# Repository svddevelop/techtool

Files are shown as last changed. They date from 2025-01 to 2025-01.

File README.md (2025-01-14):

( [RU](./README-RU.md) )
( [EN](./README.md) )
---

### TechTool

A tool built on the Raspberry Pi platform for monitoring vehicle electrical systems. It connects via the OBD2 port and uses onboard power. A smartphone, tablet, or laptop is intended to be used as the display.
Access is provided via WiFi (the Raspberry Pi works as an access point). Communication is done through a web interface or via an SSH terminal connection.

---

### Image

The image can be found in the `img` subdirectory. It is written to a USB drive of at least 4GB. It is based on the latest version of Raspberry Pi OS 64-bit.

***

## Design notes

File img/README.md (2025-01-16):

( [RU](./README-RU.md) )
( [DE](./README-DE.md) )
---

### Image
Image based on RASPBIAN OS (Debian 12)

`Linux techtool 6.6.69-v8+ #1835 SMP PREEMPT Thu Jan  2 11:27:29 GMT 2025 aarch64 GNU/Linux`

For installation on an SD card, you can use Balena Etcher, Raspberry Pi Imager, and others.

#### Connection Parameters:

- **User**: technik
- **Password**: technik
- **SSH Connection**: technik@techtool.local
- **WiFi Server IP**: 192.168.4.1

The USB-OTG port of the Raspberry Pi is configured to use the RNDIS Network. When connected to a Linux computer, it automatically connects. For Windows, you need to install a driver [such as this one](https://support.lenovo.com/ph/en/downloads/ds558735-rndis-driver-for-windows-10-lenovo-thinksystem-sr635-and-sr655).

Inside, the SPI-0.0 bus is configured with the ability to bring up the can0 interface. The following scripts are available for this:

- /usr/bin/up_can0.sh
- /usr/bin/candump_can0.sh
- /usr/bin/down_can0.sh

In addition, you can use the spi0 device directly when working with projects, for example, in Python. Do not forget to disable the can0 network interface using the down_can0.sh command before using other programs.

### WEB Interface

csws (console simple WEB server) is already installed in the system as a service **csws.service##. The file `/etc/csws.conf` contains a pre-configured setup, and by simply connecting to http://techtool.local/ or http://192.168.4.1/, the main browser page opens. It has a menu that calls pre-installed scripts. Their settings can be viewed, modified, or extended in the file `/etc/csws.conf`. Examples of HTML pages are located in the directory `/var/techtool/thtml`.

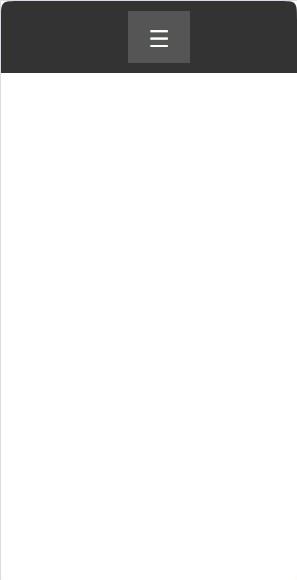
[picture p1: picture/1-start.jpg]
Start

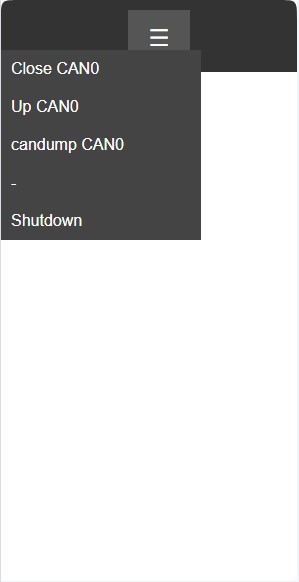
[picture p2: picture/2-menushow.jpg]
Menu

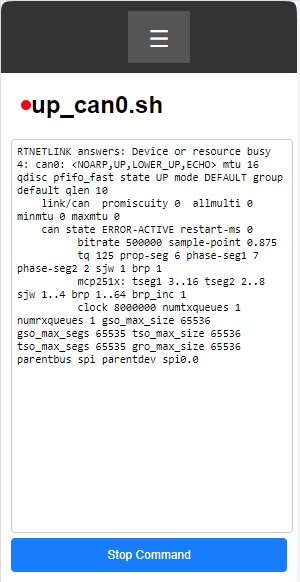
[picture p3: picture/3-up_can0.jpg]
Up can0


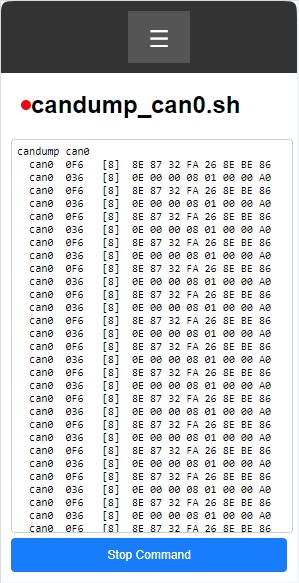
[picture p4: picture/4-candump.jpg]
candump can0

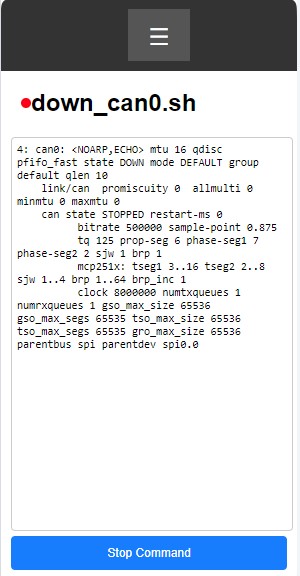
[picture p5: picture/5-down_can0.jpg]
Down can0


### Installation on Your Image

In the directory [techtool.install](./techtool.install), there are scripts for quickly making changes to the operating system files.

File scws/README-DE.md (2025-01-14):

( [RU](./README-RU.md) )
( [EN](./README.md) )
---

Der Server ist ein einfacher Skriptprozessor für Textdateien mit der Möglichkeit, Shell-Prozesse auszuführen und die Ausgabe an einen Browser zu streamen. Er kann als eigenständige Anwendung oder als Dienst betrieben werden.

### 1. Beschreibung der Hauptseite und des Skript-Interaktionsprinzips

Die Hauptseite kann neu konfiguriert werden, um eine andere Schnittstelle zu verwenden, aber hier wird erklärt, wie die Skripte miteinander interagieren.  
Die Hauptseite besteht aus einer festen Leiste mit einem Menübutton und einem Client-Bereich, in dem die Ergebnisse der ausgeführten Skripte angezeigt werden.  
Der Client-Bereich wird mit einem `<iframe>`-Element realisiert. Die Hauptseite enthält mehrere JavaScript-Hilfsfunktionen.  

Wenn der Menübutton geklickt wird, sendet die Funktion `loadMenu()` eine asynchrone AJAX-Anfrage an den Server. Nach Erhalt einer Antwort baut sie eine Baumstruktur der Menüelemente auf und zeigt sie dem Benutzer an.  

Wenn ein Menüelement ausgewählt wird, ändert JavaScript die `src`-Eigenschaft des `contentFrame` (iFrame)-Elements auf den Wert, der dem ausgewählten Menüelement entspricht. Auf diese Weise wird der Inhalt der neuen Anfrage innerhalb des Frames angezeigt.  

Eine weitere Hilfsfunktion ist `requestServer(URL)`. Sie sendet eine asynchrone Anfrage an den Server und gibt das Ergebnis zurück. Mit ihr können neue Variablen zum Server hinzugefügt, Menüelemente geändert und andere Aktionen durchgeführt werden.  

#### 1.1. Interne Server-URLs

##### 1.1.1. `/shell`
Führt einen Befehl aus, der im Parameter `cmd` übergeben wird. Implementiert in der Datei `shell.thtml`.  
Beispiel: `/shell?cmd=python myscript.py`  

##### 1.1.2. `/menulist`
Gibt eine Liste der Menüelemente und ihrer Befehle zurück. Standardmäßig werden sie aus der Konfigurationsdatei gelesen, können aber über die asynchrone Anfrage `/menu` geändert werden, die von der Funktion `requestServer()` gesendet wird.  

##### 1.1.3. `/menu`
Ermöglicht die Verwaltung des Menüs:  
- `/menu?clear` — löscht die Liste;  
- `/menu?default` — stellt die Liste aus der Konfigurationsdatei wieder her;  
- `/menu?captionX=Meine Beschriftung im Menü X&cmdX=meine URL` — ändert oder fügt ein Menüelement mit der angegebenen Beschriftung und URL hinzu.  
Alle Befehle können in einer Anfrage kombiniert werden. Sie werden in der Reihenfolge ausgeführt, die in der URL angegeben ist.  

##### 1.1.4. `/envvar`
Fügt eine neue Variable und ihren Wert zur Verwendung in Vorlagen hinzu.  
Beispiel: `/envvar?myvar=Mein Wert` — die Variable kann in der Vorlage als `$(myvar)` referenziert werden.  

##### 1.1.5. `/stop`
Beendet das Lauschen auf dem Port und beendet die Anwendung.  

##### 1.1.6. `/shellresponse`
Gibt alle ungelesenen Daten aus dem Ausgabestream zurück, nachdem ein Befehl über `/shell` ausgeführt wurde. Wenn kein Befehl ausgeführt wird, wird ein 404-Fehlercode zurückgegeben.  

##### 1.1.7. `/shellrun`
Gibt einen 200-Code zurück, wenn ein Befehl über `/shell` gestartet wurde. Andernfalls wird ein 404-Code zurückgegeben.  

### 2. Beschreibung der Konfigurationsdatei

#### 2.1. Abschnitt `Application`

##### 2.1.1. Parameter `Port`
Gibt den Port an, auf dem der Server auf Anfragen lauscht. Der Standardwert ist 8080. Bei Änderung des Ports muss der Zugriff über die Firewall konfiguriert werden. Zum Beispiel mit dem Tool `ufw`:  
```bash
sudo ufw allow 8080/tcp
```

##### 2.1.2. Parameter `RootPath`
Enthält den Pfad zum Verzeichnis mit den Vorlagen für angeforderte Seiten. Der Standardwert ist `/var/techtool/thtml/`, aber für Debugging-Zwecke kann ein anderes Verzeichnis verwendet werden.  

##### 2.1.3. Parameter `RootFileName`
Gibt den Namen der Vorlagendatei an, die beim Aufruf der URL `/` verwendet wird.  

##### 2.1.4. Parameter `WorkDir`
Enthält den Pfad zum Ordner für temporäre Dateien, wie z. B. Protokolle. Der Standardwert ist `/tmp`.  

#### 2.2. Abschnitt `MENU[X]`
Die Nummer im Abschnittsnamen ist obligatorisch und muss eindeutig sein.  

##### 2.2.1. Parameter `MenuCaption`
Enthält den Text, der dem Benutzer im Menü angezeigt wird.  

##### 2.2.2. Parameter `MenuCommand`
Enthält die URL der aufzurufenden Seite (siehe URL-Beschreibung).  

### 3. URL-Verarbeitung

Wenn ein Skriptname mit oder ohne Erweiterung angegeben wird, sucht der Server nach der Datei im Pfad, der in der Konfigurationsdatei (`APPLICATION.RootPath`) angegeben ist. Wenn die Datei nicht gefunden wird, erhält der Browser eine 404-Antwort.  

Wenn eine Seite angefordert wird, führt der Server die folgenden Substitutionen durch:  

#### 3.1. Konfigurationsvariablen
Im Skript müssen der Abschnittsname und der Parameter (ohne Trennzeichen) in Großbuchstaben angegeben werden.  
Beispiel: `$(APPLICATIONPORT)`  

#### 3.2. Umgebungsvariablen
Im Skript muss der Variablenname unter Berücksichtigung der Groß- und Kleinschreibung angegeben werden.  
Beispiel: `$(SHELL)`  

#### 3.3. Vom Entwickler definierte Variablen während der Shell-Ausführung
Die Bedingungen sind die gleichen wie für Umgebungsvariablen.  

### 4. Debugging von Skripten mit CSWS

In diesem Verzeichnis befinden sich drei vorkompilierte Versionen des Programms, die für verschiedene Plattformen entwickelt wurden:

- **`aarch64-linux`** — Version für Raspberry Pi-Geräte;
- **`x86_64-win64`** — Version für 64-Bit-Windows-Systeme;
- **`x86_64-linux`** — Version für 64-Bit-Linux-Systeme.

Das Starten der Anwendung mit einer separaten Konfigurationsdatei ermöglicht eine flexible Anpassung von Parametern und Vorlagen, was das Debugging von Skripten erleichtert. Dies ermöglicht es, ihre Funktionalität direkt im Browser zu testen, ohne Änderungen am Raspberry Pi-Gerät vornehmen zu müssen.

#### 4.1. Befehlszeilenparameter

Das Programm unterstützt die folgenden Befehlszeilenparameter:

- **`--conf="my.conf"`**  
  Startet das Programm mit der angegebenen Konfigurationsdatei. Dies ermöglicht die Verwendung von benutzerdefinierten Einstellungen und Vorlagen.

- **`--stop`**  
  Stoppt das Programm, falls es bereits ausgeführt wird.

- **`--envvar`**  
  Zeigt eine Liste aller Umgebungsvariablen an, die dem Programm zur Verfügung stehen.

- **`--addmenu="<menu caption>:=:<command>"`**  
  Fügt dem Konfigurationsdatei einen neuen Menüabschnitt hinzu.  
  - `<menu caption>` — der Menütitel;  
  - `<command>` — der mit diesem Menüpunkt verknüpfte Befehl.

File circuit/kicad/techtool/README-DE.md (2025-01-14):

( [EN](./README.md) )
( [RU](./README-RU.md) )
---

### Simplified Diagram

Alles ist mit vorgefertigten Modulen zusammengebaut, daher ist das Diagramm stark vereinfacht.

Das Diagramm zeigt die Verbindungen zwischen dem Raspberry Pi-Anschluss und dem MCP2515+TJA1050-Modul. Das Modul wird über den RPI +5V-Pin mit Strom versorgt. Allerdings weist das Modul einen Konstruktionsfehler auf und muss modifiziert werden. Die Stromversorgung für den TJA1050 sollte bei +5V bleiben, während der MCP2515 +3V3 benötigt. Der RPi-Pinout arbeitet mit 3 Volt, toleriert 5 Volt aufgrund interner Suppressoren und benötigt keinen Pegelwandler.

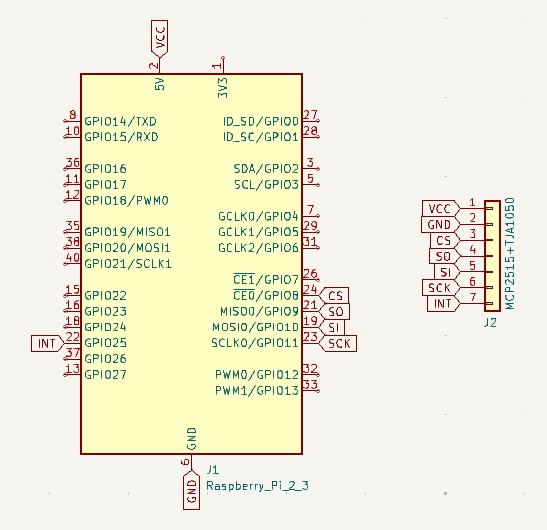
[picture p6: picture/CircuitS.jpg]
Simplified Connection Diagram


Daher wurde das MCP2515+TJA1050-Modul einigen Modifikationen unterzogen. Die Leiterbahnen auf beiden Seiten wurden durchtrennt, die Kontakte gereinigt und ein AS1117-3V3-Chip aufgelötet, um die Spannung von 5 Volt auf 3 Volt zu reduzieren.

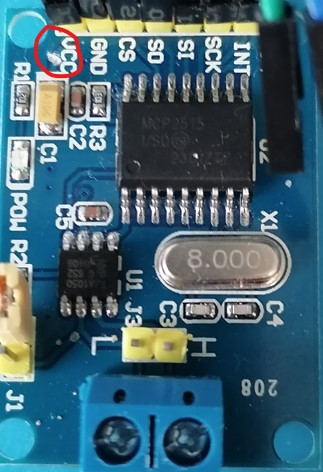
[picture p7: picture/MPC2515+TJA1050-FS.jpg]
MCP2515+TJA1050 Vorderseite

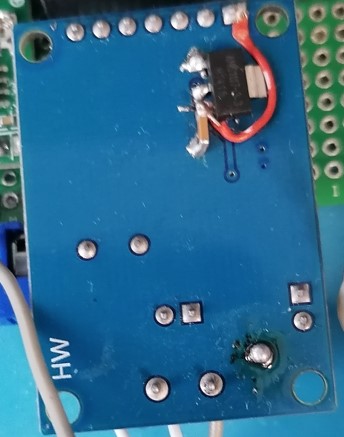
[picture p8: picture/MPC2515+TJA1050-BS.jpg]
MCP2515+TJA1050 Rückseite


>**Warning:**
Beim Anschluss der Schaltung an den OBD2-Bordstecker darf der Jumper J1 (120Ω-Terminator) nicht vergessen werden.

Da die Module über die Bordstromversorgung des OBD2-Steckers mit Strom versorgt werden müssen, wurde der MP1854 als STEP-Down-Regler gewählt, der mit einem Eingangsspannungsbereich von 5 bis 36 Volt arbeiten kann. Zusätzlich bietet er für kurze Zeit Kurzschlussschutz.

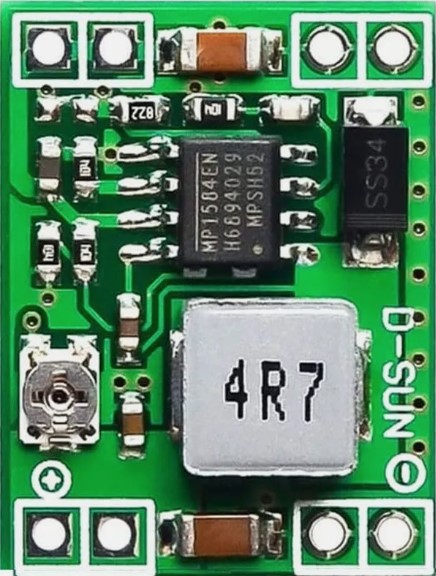
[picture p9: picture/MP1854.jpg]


Vor dem Anschluss des Reglers an den RPi muss die Ausgangsspannung mit dem Potentiometer auf den Bereich von 5 Volt eingestellt werden. Verbinden Sie ihn einfach mit den RPi +5V- und GND-Pins. Außerdem muss der GND-Pin mit Pin 4 des OBD2-Steckers verbunden werden, und der In+-Pin des Reglers muss mit Pin 16 des OBD2-Steckers verbunden werden.

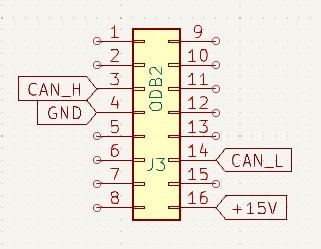
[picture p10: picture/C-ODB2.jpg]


>**Warning:**
Die Pin-Nummerierung auf dem Stecker ist im Diagramm korrekt dargestellt, aber in Wirklichkeit sind die Pins 9 bis 16 in umgekehrter Reihenfolge angeordnet, und Pin 16 befindet sich unter Pin 1.

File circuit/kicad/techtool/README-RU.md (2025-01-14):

( [EN](./README.md) )
( [DE](./README-DE.md) )
---

### Упрощенная схема

Все комплектуется готовыми блоками и потому схема сильно упрощена.

На схеме представлены соединения между разъемом Raspberry Pi и модулем MCP2515+TJA1050. Питание модуля берется с контакта RPI +5V. Но конструктивно модуля содержит ошибку и требуется его изменение. Питание для TJA1050 должно остаться +5V, а для MCP2515 требуется +3V3. RPi pinout работают с уровенем 3 вольта, толерантны к 5 вольтам за счет внутренних супрессоров, и не требуют преодразователя уровней.

Упрощенная схема соединений

Поэтому модуль MCP2515+TJA1050 получил некоторые изменения. Дорожки с двух сторон были перерезаны, контакты зачищены и напаяна микросхема AS1117-3V3_ которая и понижает напряжение с 5 вольт на 3 вольта.

MCP2515+TJA1050 Front side
MCP2515+TJA1050 Front side

>**Warning:**
При соединении схемы к бортовому разъему ODB2 не нужно забывать о включении перемычки J1 (терминатор 120Ω). 

Так как питание модулей необходимо проводить c бортового питания разъема ODB2, то в качестве STEP-Down регулятора был выбран MP1854,который может работать в диапазоне входного напряжения от 5 до 36 вольт. Помимо этого предоставляет на не продолжительное время защиту от короткого замыкания.

MP1854

Перед подключением регулятора к RPi необходимо выставить на нем выходное напряжение посредством потенционометра в диапазане 5 вольт. Просто соединить с контактами RPi +5V и GND. Также вывод GND должен соединяться с выводом 4 разъема ODB2, а вывод In+ регулятора с выводом 16 разъема ODB2.

MP1854

>**Warning:**
схематично нумерация контактов разъема указана правильно, но в реальности контакты с 9 по 16 идут в обратном направлении и вывод 16 находится под выводом 1.

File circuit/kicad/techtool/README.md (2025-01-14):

( [RU](./README-RU.md) )
( [DE](./README-DE.md) )
---

### Simplified Diagram

Everything is assembled using ready-made modules, so the diagram is greatly simplified.

The diagram shows the connections between the Raspberry Pi connector and the MCP2515+TJA1050 module. The module is powered from the RPI +5V pin. However, the module has a design flaw and requires modification. The power for the TJA1050 should remain +5V, while the MCP2515 requires +3V3. The RPi pinout operates at 3 volts, is tolerant to 5 volts due to internal suppressors, and does not require a level converter.

Simplified Connection Diagram

Therefore, the MCP2515+TJA1050 module has undergone some modifications. The traces on both sides were cut, the contacts were cleaned, and an AS1117-3V3 chip was soldered to step down the voltage from 5 volts to 3 volts.

MCP2515+TJA1050 Front Side
MCP2515+TJA1050 Back Side

>**Warning:**
When connecting the circuit to the OBD2 onboard connector, do not forget to include jumper J1 (120Ω terminator).

Since the modules need to be powered from the onboard power supply of the OBD2 connector, the MP1854 was chosen as the STEP-Down regulator, which can operate with an input voltage range of 5 to 36 volts. Additionally, it provides short-circuit protection for a short duration.

MP1854

Before connecting the regulator to the RPi, it is necessary to set the output voltage using the potentiometer to the range of 5 volts. Simply connect it to the RPi +5V and GND pins. Also, the GND pin must be connected to pin 4 of the OBD2 connector, and the In+ pin of the regulator must be connected to pin 16 of the OBD2 connector.

MP1854

>**Warning:**
The pin numbering on the connector is shown correctly in the diagram, but in reality, pins 9 to 16 are in reverse order, and pin 16 is located below pin 1.

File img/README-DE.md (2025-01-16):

( [RU](./README-RU.md) )
( [EN](./README.md) )
---

### Image
Image basierend auf RASPBIAN OS (Debian 12)

`Linux techtool 6.6.69-v8+ #1835 SMP PREEMPT Thu Jan  2 11:27:29 GMT 2025 aarch64 GNU/Linux`

Für die Installation auf einer SD-Karte können Sie Balena Etcher, Raspberry Pi Imager und andere verwenden.

#### Verbindungsparameter:

- **User**: technik
- **Password**: technik
- **SSH-Verbindung**: technik@techtool.local
- **WiFi-Server-IP**: 192.168.4.1

Der USB-OTG-Port des Raspberry Pi ist für die Verwendung des RNDIS-Netzwerks konfiguriert. Bei der Verbindung mit einem Linux-Computer erfolgt die Verbindung automatisch. Für Windows müssen Sie einen Treiber installieren, [wie zum Beispiel diesen](https://support.lenovo.com/ph/en/downloads/ds558735-rndis-driver-for-windows-10-lenovo-thinksystem-sr635-and-sr655).

Intern ist der SPI-0.0-Bus mit der Möglichkeit konfiguriert, die can0-Schnittstelle zu aktivieren. Dafür stehen folgende Skripte zur Verfügung:

- /usr/bin/up_can0.sh
- /usr/bin/candump_can0.sh
- /usr/bin/down_can0.sh

Zusätzlich können Sie das spi0-Gerät direkt verwenden, wenn Sie an Projekten arbeiten, zum Beispiel in Python. Vergessen Sie nicht, die can0-Netzwerkschnittstelle mit dem Befehl down_can0.sh zu deaktivieren, bevor Sie andere Programme verwenden.

### WEB-Oberfläche

csws (console simple WEB server) ist bereits als Dienst **csws.service## im System installiert. Die Datei `/etc/csws.conf` enthält eine vorkonfigurierte Einrichtung, und durch einfaches Verbinden mit http://techtool.local/ oder http://192.168.4.1/ öffnet sich die Hauptseite im Browser. Es gibt ein Menü, das vorkonfigurierte Skripte aufruft. Deren Einstellungen können in der Datei `/etc/csws.conf` angezeigt, geändert oder erweitert werden. Beispiele für HTML-Seiten befinden sich im Verzeichnis `/var/techtool/thtml`.

Start
Menü
Up can0

candump can0
Down can0

### Installation auf Ihrem Image

Im Verzeichnis [techtool.install](./techtool.install) befinden sich Skripte, um schnell Änderungen an den Betriebssystemdateien vorzunehmen.

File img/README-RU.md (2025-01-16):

( [EN](./README.md) )
( [DE](./README-DE.md) )

### Image
Image based on RASPBIAN OS (Debian 12)

`Linux techtool 6.6.69-v8+ #1835 SMP PREEMPT Thu Jan  2 11:27:29 GMT 2025 aarch64 GNU/Linux`

for installation on SD-Card you can use Balena Etche, Raspberry Pi Imager and etc.

#### Параметры соединения:

- **user** : technik
- **password** :technik
- **connection by ssh** : technik@techtool.local
- **WiFi-Server-IP** : 192.168.4.1

USB-OTG порт Raspberry Pi настроен на использование RNDIS Network. При подключении к компьютеру с Linux происходит автоматическое подключение. Для Windows нужно установить драйвер [например такой](https://support.lenovo.com/ph/de/downloads/ds558735-rndis-driver-for-windows-10-lenovo-thinksystem-sr635-and-sr655).

внутри настроена шина SPI-0.0 с возможностью поднять интерфейс can0. Для этого имеются следующие скрипты:

- /usr/bin/up_can0.sh
- /usr/bin/candump_can0.sh
- /usr/bin/down_can0.sh

Помимо этого можно использовать устройство spi0 напрямую при использовании проектов например на python. Не забудьте отключить сетевой интерфейс can0 командой down_can0.sh перед использованием других программ.

### WEB Interface

csws (console simple WEB server) уже установлен в сисмему в виде сервиса **csws.service##. В фале `/etc/csws.conf` имеется уже настроенная конфигурация и простым подключением http://techtool.local/ или http://192.168.4.1/ открывается основная страница браузера. На ней имеется меню, в котором вызываются предустановленные скрипты. Их настройки можно увидеть, изменить или дополнить в фале `/etc/csws.conf`. Примеры html-страниц располагаются в каталоге `/var/techtool/thtml`.

Start
Menu
Up can0

candump can0
Down can0

### установка на свой образ

в каталоге [techtool.istall](./techtool.install) расположены скрипты для быстрого внесения именений в файлы операционной системы.

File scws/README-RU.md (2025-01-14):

( [EN](./README.md) )
( [DE](./README-DE.md) )
---

Сервер представляет собой лёгкий обработчик текстовых скриптов с возможностью запуска шелл-процессов и вывода потока данных в браузер. Он может работать как отдельное приложение или как сервис.

### 1. Описание основной страницы и принцип взаимодействия скриптов

Основная страница может быть перенастроена для использования другого интерфейса, но здесь объясняется, как взаимодействуют скрипты между собой.  
Основная страница состоит из фиксированной панели с кнопкой меню и клиентской части, где отображаются результаты выполнения вызываемых скриптов.  
Клиентская часть реализована с использованием элемента `<iframe>`. Основная страница содержит несколько вспомогательных функций на JavaScript.  

При нажатии на кнопку меню функция `loadMenu()` отправляет асинхронный AJAX-запрос на сервер. Получив ответ, она строит дерево элементов меню и отображает его пользователю.  

При выборе элемента меню JavaScript изменяет свойство `src` элемента `contentFrame` (iFrame) на значение, соответствующее выбранному элементу меню. Таким образом, содержимое нового запроса отображается внутри фрейма.  

Ещё одна вспомогательная функция — `requestServer(URL)`. Она выполняет асинхронный запрос к серверу и возвращает результат. С её помощью можно добавлять новые переменные на сервер, изменять элементы меню и выполнять другие действия.  

#### 1.1. Внутренние URL сервера

##### 1.1.1. `/shell`
Запускает команду, переданную в параметре `cmd`. Реализовано в файле `shell.thtml`.  
Пример: `/shell?cmd=python myscript.py`  

##### 1.1.2. `/menulist`
Возвращает список элементов меню и их команд. По умолчанию они считываются из конфигурационного файла, но могут быть изменены с помощью запроса `/menu`, отправленного асинхронно функцией `requestServer()`.  

##### 1.1.3. `/menu`
Позволяет управлять меню:  
- `/menu?clear` — очищает список;  
- `/menu?default` — восстанавливает список из конфигурационного файла;  
- `/menu?captionX=My caption in menu X&cmdX=my URL` — изменяет или добавляет элемент меню с указанным заголовком и URL.  
Все команды можно комбинировать в одном запросе. Они выполняются в порядке, указанном в URL.  

##### 1.1.4. `/envvar`
Добавляет новую переменную и её значение для использования в шаблонах.  
Пример: `/envvar?myvar=My value` — переменная может быть вызвана в шаблоне как `$(myvar)`.  

##### 1.1.5. `/stop`
Останавливает прослушивание порта и завершает работу приложения.  

##### 1.1.6. `/shellresponse`
Возвращает все непрочитанные данные из потока вывода после выполнения команды через `/shell`. Если команда не выполняется, возвращается код ошибки 404.  

##### 1.1.7. `/shellrun`
Возвращает код 200, если команда была запущена через `/shell`. В противном случае возвращает код 404.  

### 2. Описание конфигурационного файла

#### 2.1. Секция `Application`

##### 2.1.1. Параметр `Port`
Указывает порт, на котором сервер будет прослушивать запросы. По умолчанию — 8080. При изменении порта необходимо настроить доступ через брандмауэр. Например, с помощью утилиты `ufw`:  
```bash
sudo ufw allow 8080/tcp
```

##### 2.1.2. Параметр `RootPath`
Содержит путь к каталогу с шаблонами запрашиваемых страниц. По умолчанию — `/var/techtool/thtml/`, но для отладки можно использовать любой другой.  

##### 2.1.3. Параметр `RootFileName`
Указывает имя файла шаблона, который будет использоваться при вызове URL `/`.  

##### 2.1.4. Параметр `WorkDir`
Содержит путь к папке для временных файлов, например логов. По умолчанию — `/tmp`.  

#### 2.2. Секция `MENU[X]`
Номер в названии секции обязателен и не должен повторяться.  

##### 2.2.1. Параметр `MenuCaption`
Содержит текст, отображаемый пользователю в меню.  

##### 2.2.2. Параметр `MenuCommand`
Содержит URL вызываемой страницы (см. описание URL).  

### 3. Обработка URL

При указании имени скрипта с расширением или без него производится поиск файла по пути, указанному в конфигурационном файле (`APPLICATION.RootPath`). Если файл не найден, браузер получает ответ с кодом 404.  

При запросе страницы сервер выполняет поиск и подстановку значений:  

#### 3.1. Конфигурационных переменных
В скрипте необходимо указать имя секции и параметра (без разделителя) в верхнем регистре.  
Например: `$(APPLICATIONPORT)`  

#### 3.2. Переменных окружения
В скрипте необходимо указать имя переменной с учётом регистра.  
Например: `$(SHELL)`  

#### 3.3. Переменных, заданных разработчиком при вызове шелла
Условия такие же, как и для переменных окружения.  

### 4. Отладка скриптов совместно с CSWS

В этом каталоге находятся три предварительно скомпилированные версии программы, предназначенные для разных платформ:

- **`aarch64-linux`** — версия для устройств на базе Raspberry Pi;
- **`x86_64-win64`** — версия для 64-битных систем Windows;
- **`x86_64-linux`** — версия для 64-битных систем Linux.

Запуск приложения с отдельным конфигурационным файлом позволяет гибко настраивать параметры и шаблоны, что упрощает отладку скриптов. Это дает возможность проверять их работу непосредственно в браузере без необходимости внесения изменений на устройстве Raspberry Pi.

#### 4.1. Параметры командной строки

Программа поддерживает следующие параметры командной строки:

- **`--conf="my.conf"`**  
  Запуск программы с использованием указанного конфигурационного файла. Это позволяет использовать индивидуальные настройки и шаблоны.

- **`--stop`**  
  Останавливает работу программы, если она уже запущена.

- **`--envvar`**  
  Выводит список всех переменных окружения, доступных для программы.

- **`--addmenu="<menu caption>:=:<command>"`**  
  Добавляет новую секцию меню в конфигурационный файл.  
  - `<menu caption>` — заголовок меню;  
  - `<command>` — команда, связанная с этим пунктом меню.

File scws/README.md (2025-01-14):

( [RU](./README-RU.md) )
( [DE](./README-DE.md) )
---

The server is a lightweight script processor for text files with the ability to run shell processes and stream the output to a browser. It can operate as a standalone application or as a service.

### 1. Description of the Main Page and Script Interaction Principle

The main page can be reconfigured to use a different interface, but here we explain how the scripts interact with each other.  
The main page consists of a fixed panel with a menu button and a client area where the results of the executed scripts are displayed.  
The client area is implemented using an `<iframe>` element. The main page contains several JavaScript helper functions.  

When the menu button is clicked, the `loadMenu()` function sends an asynchronous AJAX request to the server. Upon receiving a response, it builds a tree of menu items and displays it to the user.  

When a menu item is selected, JavaScript changes the `src` property of the `contentFrame` (iFrame) element to the value corresponding to the selected menu item. This way, the content of the new request is displayed inside the frame.  

Another helper function is `requestServer(URL)`. It performs an asynchronous request to the server and returns the result. It can be used to add new variables to the server, modify menu items, and perform other actions.  

#### 1.1. Internal Server URLs

##### 1.1.1. `/shell`
Executes a command passed in the `cmd` parameter. Implemented in the `shell.thtml` file.  
Example: `/shell?cmd=python myscript.py`  

##### 1.1.2. `/menulist`
Returns a list of menu items and their commands. By default, they are read from the configuration file, but they can be modified using the `/menu` request sent asynchronously by the `requestServer()` function.  

##### 1.1.3. `/menu`
Allows managing the menu:  
- `/menu?clear` — clears the list;  
- `/menu?default` — restores the list from the configuration file;  
- `/menu?captionX=My caption in menu X&cmdX=my URL` — modifies or adds a menu item with the specified caption and URL.  
All commands can be combined in a single request. They are executed in the order specified in the URL.  

##### 1.1.4. `/envvar`
Adds a new variable and its value for use in templates.  
Example: `/envvar?myvar=My value` — the variable can be referenced in the template as `$(myvar)`.  

##### 1.1.5. `/stop`
Stops listening on the port and terminates the application.  

##### 1.1.6. `/shellresponse`
Returns all unread data from the output stream after executing a command via `/shell`. If no command is running, a 404 error code is returned.  

##### 1.1.7. `/shellrun`
Returns a 200 code if a command was launched via `/shell`. Otherwise, it returns a 404 code.  

### 2. Description of the Configuration File

#### 2.1. `Application` Section

##### 2.1.1. `Port` Parameter
Specifies the port on which the server will listen for requests. The default is 8080. When changing the port, ensure firewall access is configured. For example, using the `ufw` utility:  
```bash
sudo ufw allow 8080/tcp
```

##### 2.1.2. `RootPath` Parameter
Contains the path to the directory with the templates for requested pages. The default is `/var/techtool/thtml/`, but any other directory can be used for debugging.  

##### 2.1.3. `RootFileName` Parameter
Specifies the name of the template file to be used when the URL `/` is called.  

##### 2.1.4. `WorkDir` Parameter
Contains the path to the folder for temporary files, such as logs. The default is `/tmp`.  

#### 2.2. `MENU[X]` Section
The number in the section name is mandatory and must be unique.  

##### 2.2.1. `MenuCaption` Parameter
Contains the text displayed to the user in the menu.  

##### 2.2.2. `MenuCommand` Parameter
Contains the URL of the page to be called (see URL description).  

### 3. URL Processing

When specifying a script name with or without an extension, the server searches for the file in the path specified in the configuration file (`APPLICATION.RootPath`). If the file is not found, the browser receives a 404 response.  

When a page is requested, the server performs the following substitutions:  

#### 3.1. Configuration Variables
In the script, specify the section name and parameter (without a separator) in uppercase.  
For example: `$(APPLICATIONPORT)`  

#### 3.2. Environment Variables
In the script, specify the variable name with case sensitivity.  
For example: `$(SHELL)`  

#### 3.3. Variables Defined by the Developer During Shell Execution
The conditions are the same as for environment variables.  

### 4. Debugging Scripts with CSWS

This directory contains three pre-compiled versions of the program, designed for different platforms:

- **`aarch64-linux`** — version for Raspberry Pi devices;
- **`x86_64-win64`** — version for 64-bit Windows systems;
- **`x86_64-linux`** — version for 64-bit Linux systems.

Launching the application with a separate configuration file allows for flexible customization of parameters and templates, making it easier to debug scripts. This enables testing their functionality directly in a browser without the need to make changes on the Raspberry Pi device.

#### 4.1. Command Line Parameters

The program supports the following command-line parameters:

- **`--conf="my.conf"`**  
  Launches the program using the specified configuration file. This allows for the use of custom settings and templates.

- **`--stop`**  
  Stops the program if it is already running.

- **`--envvar`**  
  Displays a list of all environment variables available to the program.

- **`--addmenu="<menu caption>:=:<command>"`**  
  Adds a new menu section to the configuration file.  
  - `<menu caption>` — the menu title;  
  - `<command>` — the command associated with this menu item.

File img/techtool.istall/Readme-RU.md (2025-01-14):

( [EN](./README.md) )
( [DE](./README-DE.md) )
---

### файлы для быстрой установки

##### Эти файлы обязательны для настройки системы:

- 1-change_etc-dhcpcd.sh
- 2-change_etc-dnsmasq.sh
- 3-change_etc_hostapd_hostapd.sh
- 4-install_csws_asservice.sh
- 5-do_copy_thtml.sh
- 6-create_setup_can0.sh
- 7-create_stop_can0.sh

##### Эти файлы лучше изменять вручную:

- change_cmdline.sh
- change_config.sh

##### Эти файлы использовать при необходимости:

- change_etc_sysctl.sh
- change_waitForNetwork.sh

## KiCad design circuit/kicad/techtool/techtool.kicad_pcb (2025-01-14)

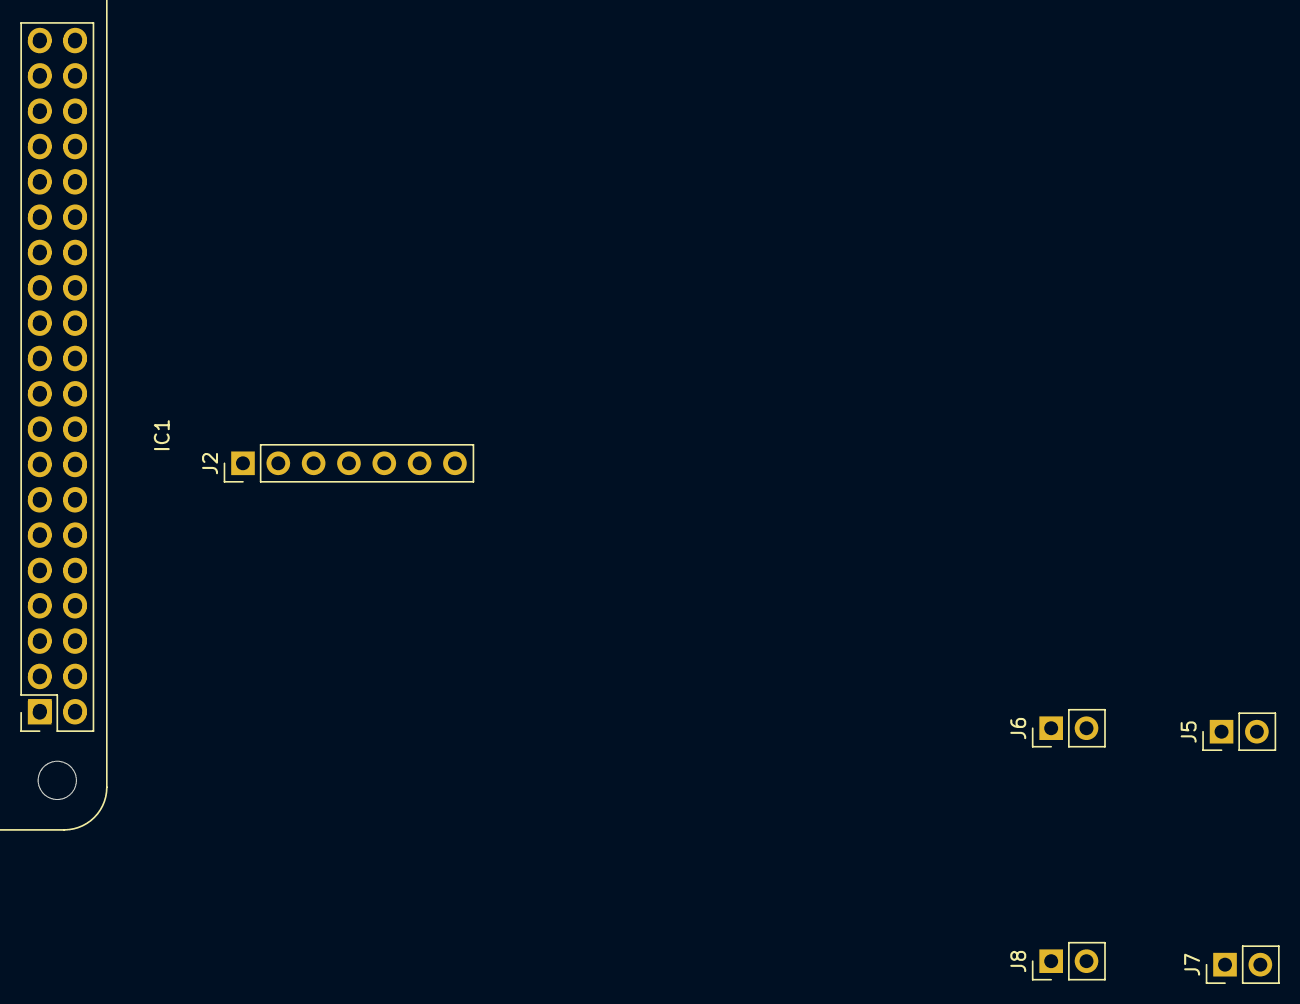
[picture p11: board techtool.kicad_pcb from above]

Board: 2 copper layers, 7 parts (1 on the bottom side), 8 nets, no tracks yet.

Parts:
IC1: Raspberry_Pi_Zero_W_(v1.3); Raspberry_Pi_Zero_Socketed_THT_FaceDown_MountingHoles
J1: Raspberry_Pi_2_3; PinHeader_2x20_P2.54mm_Vertical
J2: MCP2515+TJA1050; PinHeader_1x07_P2.54mm_Vertical
J5: VCC; PinHeader_1x02_P2.54mm_Vertical
J6: GND; PinHeader_1x02_P2.54mm_Vertical
J7: In+; PinHeader_1x02_P2.54mm_Vertical
J8: In-; PinHeader_1x02_P2.54mm_Vertical

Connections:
CS: J1.24 (~CE0/GPIO8), J2.3
GND: J1.6 (GND), J1.9 (GND), J1.14 (GND), J1.20 (GND), J1.25 (GND), J1.30 (GND), J1.34 (GND), J1.39 (GND), J2.2, J6.2
INT: J1.22 (GPIO25), J2.7
unnamed: J1.1 (3V3), J1.17 (3V3)
SCK: J1.23 (SCLK0/GPIO11), J2.6
SI: J1.19 (MOSI0/GPIO10), J2.5
SO: J1.21 (MISO0/GPIO9), J2.4
VCC: J1.2 (5V), J1.4 (5V), J2.1, J5.1

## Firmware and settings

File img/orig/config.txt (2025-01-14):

gpio=8=op,dh
dtparam=spi=off
#dtoverlay=spi-bcm2835-overlay
#dtoverlay=spi0-1cs,cs0_pin=8
dtoverlay=spi0-1cs
dtoverlay=mcp2515-can0,spi0-0,oscillator=16000000,interrupt=25
#,bitrate=500000




dtoverlay=dwc2

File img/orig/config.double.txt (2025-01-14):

# 
# MCP INT --> RPi 22 (GPIO 25); MCP SI --> RPi 19 (GPIO 10); MCP SO --> RPi 21 (GPIO 9)
# MCP SCK --> RPi 23 (GPIO 11); MCP CS --> RPi 24 (GPIO 8)
#

dtparam=spi=on
dtoverlay=mcp2515-can0,oscillator=8000000,interrupt=25

#
# MCP INT --> RPi 37 (GPIO 26); MCP SI --> RPi 38 (GPIO ); MCP SO --> RPi 35 (GPIO )
# MCP SCK --> RPi 40 (GPIO ); MCP CS --> RPi 36 (GPIO 16)
#
# https://github.com/terilenard/mcp2515-tja1050-wiring
dtoverlay=spi1-1cs,cs0_pin=16,cs0_spidev=off
dtoverlay=mcp2515-can2,oscillator=8000000,interrupt=26

#
dtoverlay=spi-bcm2835-overlay

dtoverlay=dwc2
